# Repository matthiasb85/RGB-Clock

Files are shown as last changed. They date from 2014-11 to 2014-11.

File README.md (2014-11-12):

RGB-Clock
=========

RGB-Clock with STM32F1, DCF77, ESP8266, IR RC5 and LDR.

The following features are implemented (1-3) or will be implemented later (4-7)

1.) Fast STM32F103 @72MHz

2.) WS2812B RGB stripe, controlled via PWM & DMA (~0% CPU usage)

3.) DCF77 receiver for time snych

4.) ESP8266 Wifi module for HTTP interface and NTP time synch

5.) IR RC5 receiver integration

6.) Ambient dependent lighting with LDR

7.) MicroSD Card as storage device

The board uses a standard ARM JTAG interface. In addition all remaining GPIOs and the ESP8266 are available on an external pinheader.

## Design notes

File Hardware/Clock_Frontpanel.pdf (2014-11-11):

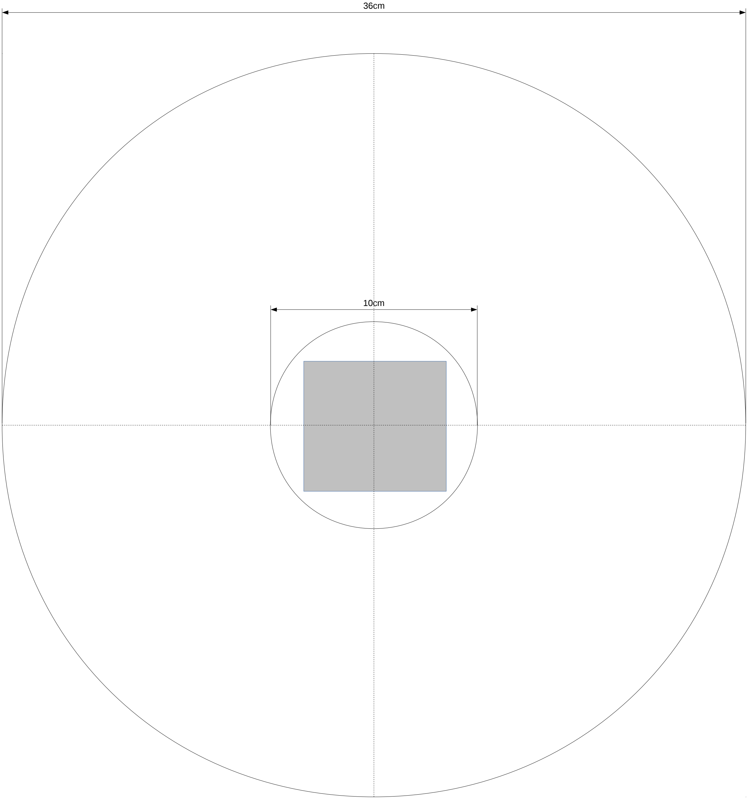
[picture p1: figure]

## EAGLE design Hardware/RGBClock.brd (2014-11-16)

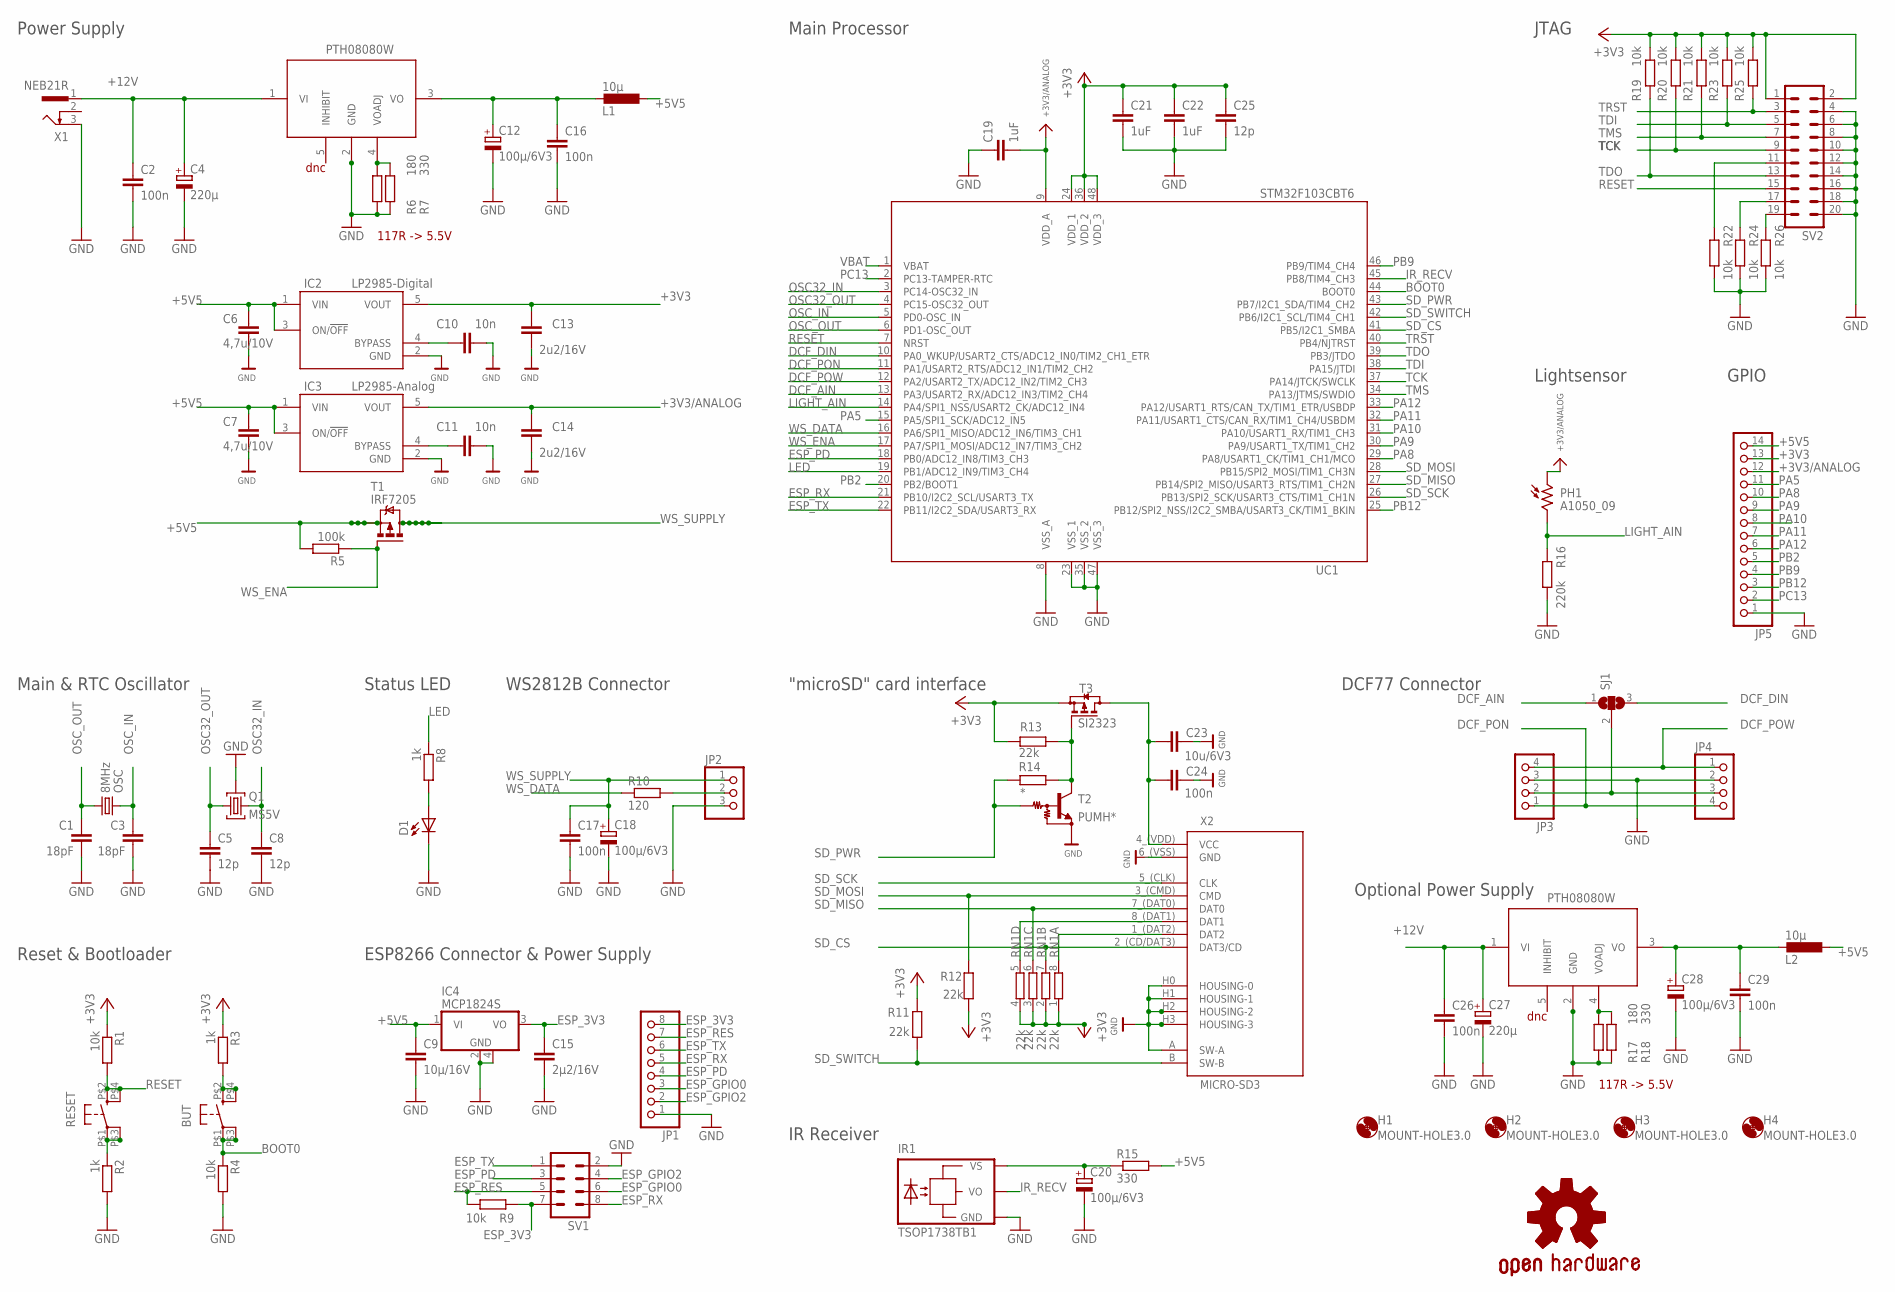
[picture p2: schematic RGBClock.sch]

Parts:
BUT: KMR211GLFS; PUSHBUTTON-KMR241GLFS
C1, C3: 18pF; C0402
C2, C16, C17, C26, C29: 100n; C0603
C4, C27: 220µ; E3,5-8
C5, C8, C25: 12p; C0603
C6, C7: 4,7u/10V; C0603-DASHES
C9: 10µ/16V; C0805
C10, C11: 10n; C0603-DASHES
C12, C18, C20, C28: 100µ/6V3; PANASONIC_C
C13, C14: 2u2/16V; C0603-DASHES
C15: 2µ2/16V; C0603
C19, C21, C22: 1uF; C0603
C23: 10u/6V3; C0603-DASHES
C24: 100n; C0603-DASHES
D1: Blue; LED-1206
GOLD_ORB_SM1: OSHWLOGO_GOLD_ORB_MED; OSHW1
H1, H2, H3, H4: MOUNT-HOLE3.0; 3,0
IC1, IC5: PTH08080W
IC2: LP2985-Digital; SOT23-5
IC3: LP2985-Analog; SOT23-5
IC4: MCP1824S; SOT223
IR1: TSOP1738TB1; TSOP17_TB1
JP1: PINHD-1X8/90; 1X08/90
JP2: PINHD-1X3/90; 1X03/90
JP3, JP4: PINHD-1X4; 1X04
JP5: PINHD-1X14/90; 1X14/90
L1, L2: 10µ; SD53-XXX-R; DIGIKEY-PN 513-1457-1-ND
OSC: 8MHz; CRYSTAL-SMD-5X3
PH1: A1050_09; T0-46-A10XX
Q1: MS5V
R1, R4, R9, R19, R20, R21, R22, R23, R24, R25, R26: 10k; R0603
R2, R3, R8: 1k; R0603
R5: 100k; R0603
R6, R17: 180; R0603
R7, R15, R18: 330; R0603
R10: 120; R0603
R11, R12, R13: 22k; R0603-DASHES
R14: *; R0603-DASHES
R16: 220k; R0603
RESET: KMR211GLFS; PUSHBUTTON-KMR241GLFS
RN1: 22k; CRA3A4E; PART_TYPE EXB-N8V
SJ1: SJ2W0603; JUM0603
SV1: MA04-2
SV2: ML20L
T1: IRF7205; SO-08
T2: PUMH*; SOT23
T3: SI2323; SOT23
UC1: STM32F103CBT6; LQFP48
X1: NEB21R
X2: MICRO-SD3; HIROSE_DM3AT

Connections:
+3V3: C13.1, C21.1, C22.1, C25.1, IC2.5 (VOUT), JP5.13, R1.1, R3.1, R11.2, R12.2, R13.2, R19.1, R20.1, R21.1, R23.1, R25.1, RN1.1, RN1.2 (1), RN1.3 (1), RN1.4 (1), SV2.1, SV2.2, T3.2 (S), UC1.24 (VDD_1), UC1.36 (VDD_2), UC1.48 (VDD_3)
+3V3/ANALOG: C14.1, C19.2, IC3.5 (VOUT), JP5.12, PH1.1, UC1.9 (VDD_A)
+5V5: C6.1, C7.1, C9.1, IC2.1 (VIN), IC2.3 (ON/!OFF), IC3.1 (VIN), IC3.3 (ON/!OFF), IC4.1 (VI), JP5.14, L1.1, L2.1, R5.2, R15.2, T1.1 (S), T1.2 (S), T1.3 (S)
+6V_EXT: C12.+, C16.1, IC1.3 (VO), L1.2
+6V_EXT1: C28.+, C29.1, IC5.3 (VO), L2.2
+12V: C2.1, C4.+, C26.1, C27.+, IC1.1 (VI), IC5.1 (VI), X1.1
BOOT0: BUT.P$1 (1), BUT.P$3 (3), R4.1, UC1.44 (BOOT0)
DCF_AIN: SJ1.1, UC1.13 (PA3/USART2_RX/ADC12_IN3/TIM2_CH4)
DCF_DIN: SJ1.3, UC1.10 (PA0_WKUP/USART2_CTS/ADC12_IN0/TIM2_CH1_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)
DCF_PON: JP3.1, JP4.4, UC1.11 (PA1/USART2_RTS/ADC12_IN1/TIM2_CH2)
DCF_POW: JP3.4, JP4.1, UC1.12 (PA2/USART2_TX/ADC12_IN2/TIM2_CH3)
ESP_3V3: C15.1, IC4.3 (VO), JP1.8, R9.2, SV1.7
ESP_GPIO0: JP1.3, SV1.6
ESP_GPIO2: JP1.2, SV1.4
ESP_PD: JP1.4, SV1.3, UC1.18 (PB0/ADC12_IN8/TIM3_CH3)
ESP_RES: JP1.7, R9.1, SV1.5
ESP_RX: JP1.5, SV1.8, UC1.21 (PB10/I2C2_SCL/USART3_TX)
ESP_TX: JP1.6, SV1.1, UC1.22 (PB11/I2C2_SDA/USART3_RX)
GND: C1.2, C2.2, C3.2, C4.-, C5.2, C6.2, C7.2, C8.2, C9.2, C10.2, C11.2, C12.-, C13.2, C14.2, C15.2, C16.2, C17.2, C18.-, C19.1, C20.-, C21.2, C22.2, C23.2, C24.2, C25.2, C26.2, C27.-, C28.-, C29.2, D1.C, IC1.2 (GND), IC2.2 (GND), IC3.2 (GND), IC4.2 (GND), IC4.4 (GND), IC5.2 (GND), IR1.GND, JP1.1, JP2.3, JP3.3, JP4.2, JP5.1, Q1.H (3), R2.2, R4.2, R6.2, R7.2, R16.1, R17.2, R18.2, R22.1, R24.1, R26.1, SV1.2, SV2.4, SV2.6, SV2.8, SV2.10, SV2.12, SV2.14, SV2.16, SV2.18, SV2.20, T2.2 (E), UC1.8 (VSS_A), UC1.23 (VSS_1), UC1.35 (VSS_2), UC1.47 (VSS_3), X1.3, X2.6_(VSS) (GND), X2.A (SW-A), X2.H0 (HOUSING-0), X2.H1 (HOUSING-1), X2.H2 (HOUSING-2), X2.H3 (HOUSING-3)
IR_RECV: IR1.VO, UC1.45 (PB8/TIM4_CH3)
LED: R8.1, UC1.19 (PB1/ADC12_IN9/TIM3_CH4)
LIGHT_AIN: PH1.2, R16.2, UC1.14 (PA4/SPI1_NSS/USART2_CK/ADC12_IN4)
LP2985_BYPASS: C11.1, IC3.4 (BYPASS)
LP2985_BYPASS1: C10.1, IC2.4 (BYPASS)
unnamed: BUT.P$2 (2), BUT.P$4 (4), R3.2
unnamed: D1.A, R8.2
unnamed: JP2.2, R10.2
unnamed: R2.1, RESET.P$1 (1), RESET.P$3 (3)
unnamed: IC5.4 (VOADJ), R17.1, R18.1
unnamed: R26.2, SV2.19
unnamed: JP3.2, JP4.3, SJ1.2
unnamed: R24.2, SV2.17
unnamed: R22.2, SV2.11
unnamed: C20.+, IR1.VS, R15.1
unnamed: RN1.8 (2), X2.1_(DAT2) (DAT2)
unnamed: RN1.5 (2), X2.8_(DAT1) (DAT1)
unnamed: IC1.4 (VOADJ), R6.1, R7.1
OSC32_IN: C8.1, Q1.2, UC1.3 (PC14-OSC32_IN)
OSC32_OUT: C5.1, Q1.1, UC1.4 (PC15-OSC32_OUT)
OSC_IN: C3.1, OSC.3 (2), UC1.5 (PD0-OSC_IN)
OSC_OUT: C1.1, OSC.1, UC1.6 (PD1-OSC_OUT)
PA5: JP5.11, UC1.15 (PA5/SPI1_SCK/ADC12_IN5)
PA8: JP5.10, UC1.29 (PA8/USART1_CK/TIM1_CH1/MCO)
PA9: JP5.9, UC1.30 (PA9/USART1_TX/TIM1_CH2)
PA10: JP5.8, UC1.31 (PA10/USART1_RX/TIM1_CH3)
PA11: JP5.7, UC1.32 (PA11/USART1_CTS/CAN_RX/TIM1_CH4/USBDM)
PA12: JP5.6, UC1.33 (PA12/USART1_RTS/CAN_TX/TIM1_ETR/USBDP)
PB2: JP5.5, UC1.20 (PB2/BOOT1)
PB9: JP5.4, UC1.46 (PB9/TIM4_CH4)
PB12: JP5.3, UC1.25 (PB12/SPI2_NSS/I2C2_SMBA/USART3_CK/TIM1_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)
PC13: JP5.2, UC1.2 (PC13-TAMPER-RTC)
RESET: R1.2, RESET.P$2 (2), RESET.P$4 (4), SV2.15, UC1.7 (NRST)
SDIO_VCC: C23.1, C24.1, T3.3 (D), X2.4_(VDD) (VCC)
SD_CS: RN1.7 (2), UC1.41 (PB5/I2C1_SMBA), X2.2_(CD/DAT3) (DAT3/CD)
SD_MISO: RN1.6 (2), UC1.27 (PB14/SPI2_MISO/USART3_RTS/TIM1_CH2N), X2.7_(DAT0) (DAT0)
SD_MOSI: R12.1, UC1.28 (PB15/SPI2_MOSI/TIM1_CH3N), X2.3_(CMD) (CMD)
SD_PWR: R14.2, T2.1 (B), UC1.43 (PB7/I2C1_SDA/TIM4_CH2)
SD_PWR_INV: R13.1, R14.1, T2.3 (C), T3.1 (G)
SD_SCK: UC1.26 (PB13/SPI2_SCK/USART3_CTS/TIM1_CH1N), X2.5_(CLK) (CLK)
SD_SWITCH: R11.1, UC1.42 (PB6/I2C1_SCL/TIM4_CH1), X2.B (SW-B)
TCK: R20.2, SV2.9, UC1.37 (PA14/JTCK/SWCLK)
TDI: R23.2, SV2.5, UC1.38 (PA15/JTDI)
TDO: R19.2, SV2.13, UC1.39 (PB3/JTDO)
TMS: R21.2, SV2.7, UC1.34 (PA13/JTMS/SWDIO)
TRST: R25.2, SV2.3, UC1.40 (PB4/NJTRST)
VBAT: UC1.1 (VBAT)
WS_DATA: R10.1, UC1.16 (PA6/SPI1_MISO/ADC12_IN6/TIM3_CH1)
WS_ENA: R5.1, T1.4 (G), UC1.17 (PA7/SPI1_MOSI/ADC12_IN7/TIM3_CH2)
WS_SUPPLY: C17.1, C18.+, JP2.1, T1.5 (D), T1.6 (D), T1.7 (D), T1.8 (D)

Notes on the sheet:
PTH08080W
117R -> 5.5V
dnc
"microSD" card interface
Power Supply
Main Processor
Main & RTC Oscillator
Reset & Bootloader
DCF77 Connector
Status LED
WS2812B Connector
IR Receiver
ESP8266 Connector & Power Supply
JTAG
Lightsensor
GPIO
Optional Power Supply

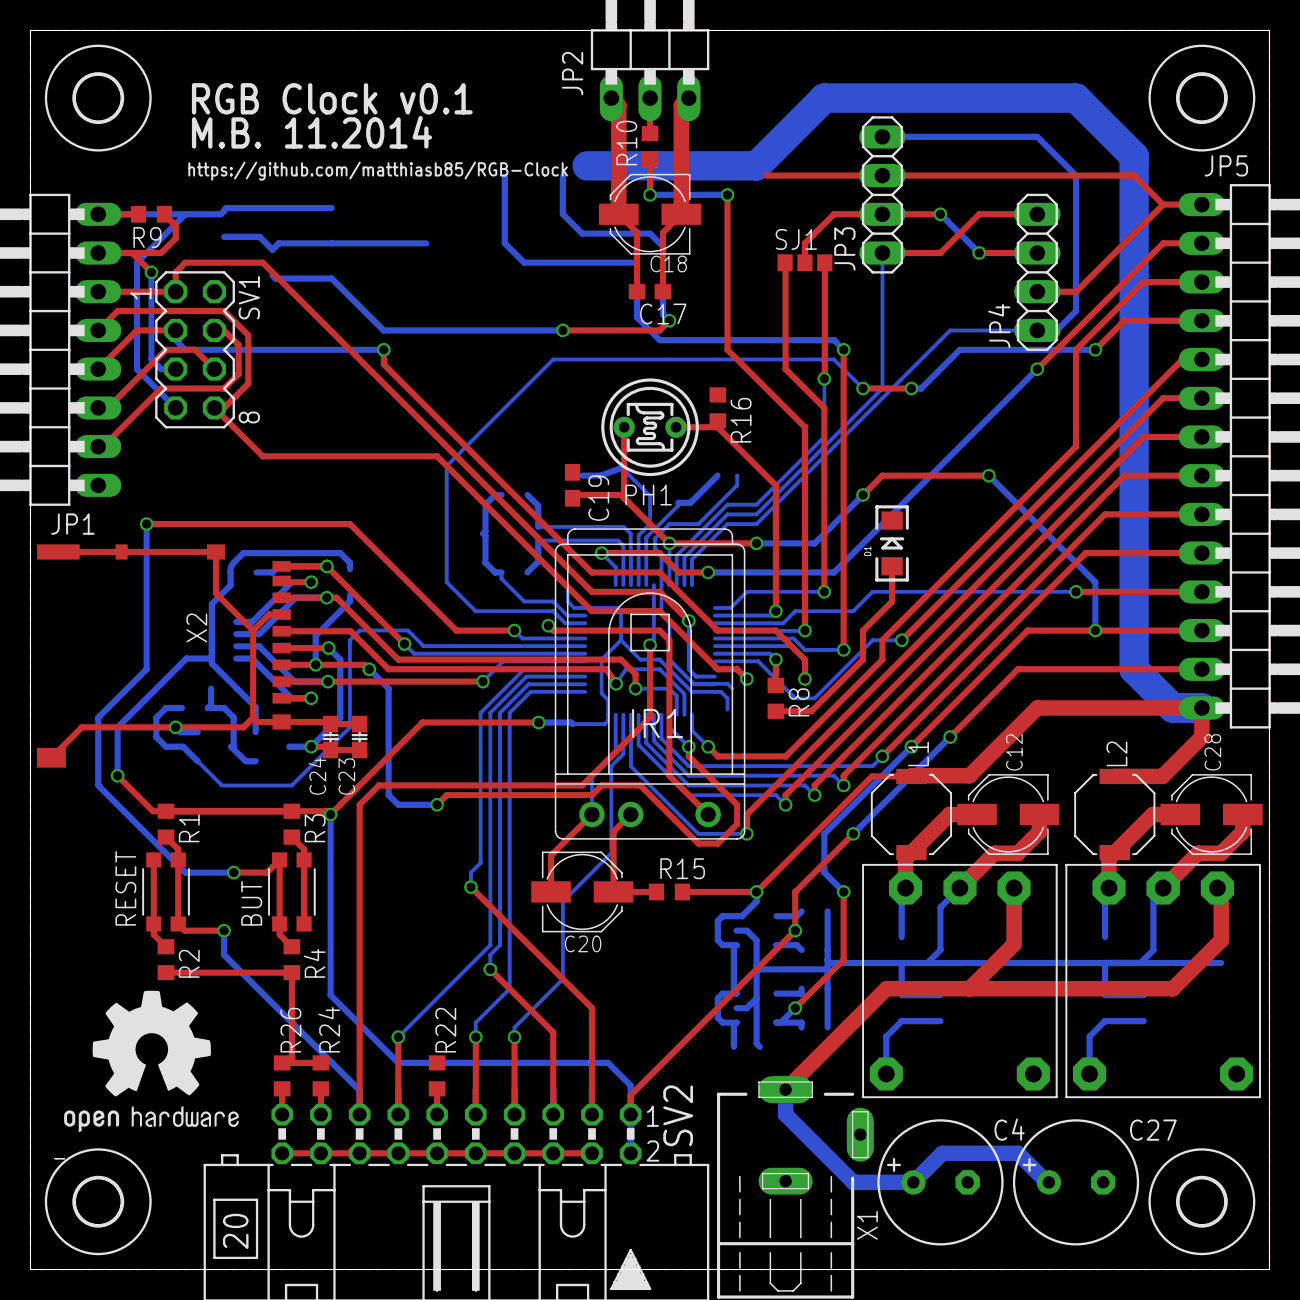
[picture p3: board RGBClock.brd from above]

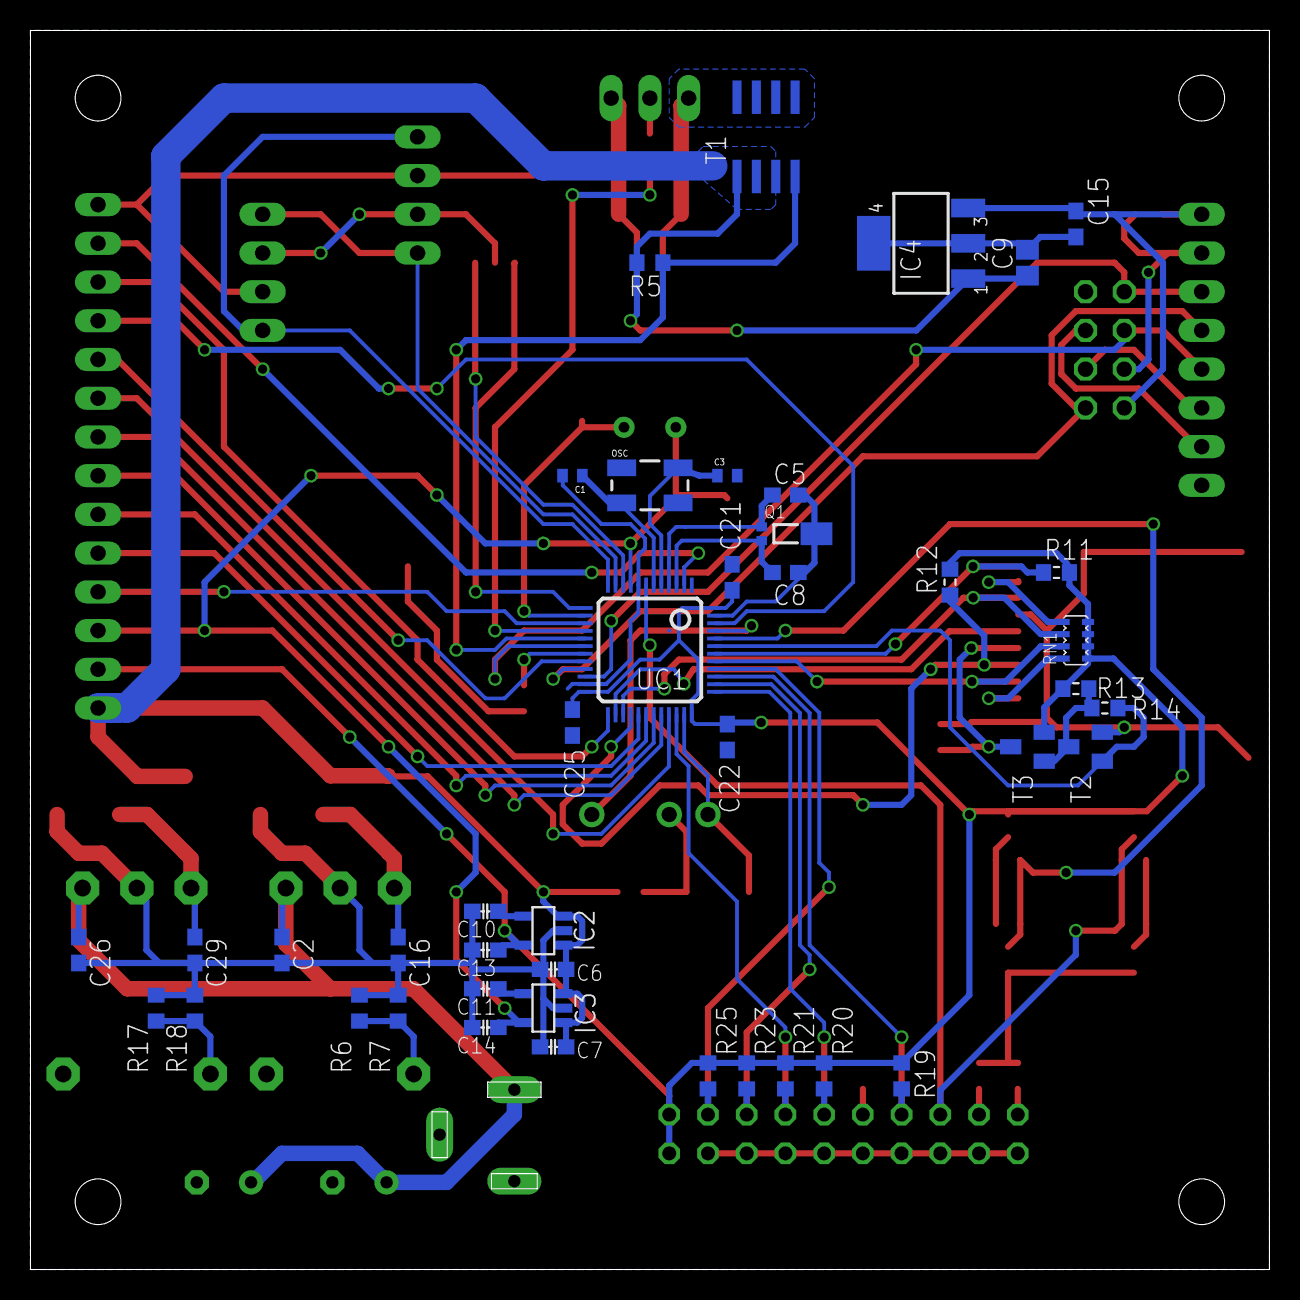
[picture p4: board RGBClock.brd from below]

Board: 2 copper layers, 81.3 x 81.3 mm, 89 parts (43 on the bottom side), 68 nets.

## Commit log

2014-11-11 added first version of PCB added frontpanel
    [RGBClock.brd, RGBClock.sch]
2014-11-11 added github url on PCB
    [RGBClock.brd]
2014-11-15 worked on board worked on silkscreen -> first version should be ready within a few commits
    [RGBClock.brd, RGBClock.sch]
2014-11-16 minor changes on board and schematic
    [RGBClock.brd, RGBClock.sch]
2014-11-16 modified board, better placement for C21,22,25
    [RGBClock.brd]
2014-11-16 minor changes on silkscreen
    [RGBClock.brd]
